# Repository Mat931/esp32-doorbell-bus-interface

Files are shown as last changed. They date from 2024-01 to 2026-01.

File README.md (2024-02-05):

# ESP32 Bus Interface for ABB-Welcome and Busch-Welcome 
This device allows you to integrate your ABB-Welcome or Busch-Welcome 2-wire doorbell intercom system into Home Assistant. Features include doorbell notifications and remotely opening your door. You can order the fully assembled board from a PCB manufacturer.

[How to order](https://github.com/Mat931/esp32-doorbell-bus-interface/blob/main/how_to_order.md)

[How to flash with ESPHome](https://github.com/Mat931/esp32-doorbell-bus-interface/blob/main/how_to_flash.md)

[How to customize for your system](https://github.com/Mat931/esp32-doorbell-bus-interface/blob/main/how_to_customize.md)

### Example applications
- Get notified when someone rings your doorbell
- Open your front door using your smartphone
- Build external door opener buttons that also stop the doorbell ringtone
- Turn on the hallway lights from Home Assistant
- Send and receive any control message on the ABB-Welcome 2-wire bus

### Limitations
- Only works with 2-wire systems, not ABB-Welcome IP
- Audio and video is not supported by this hardware

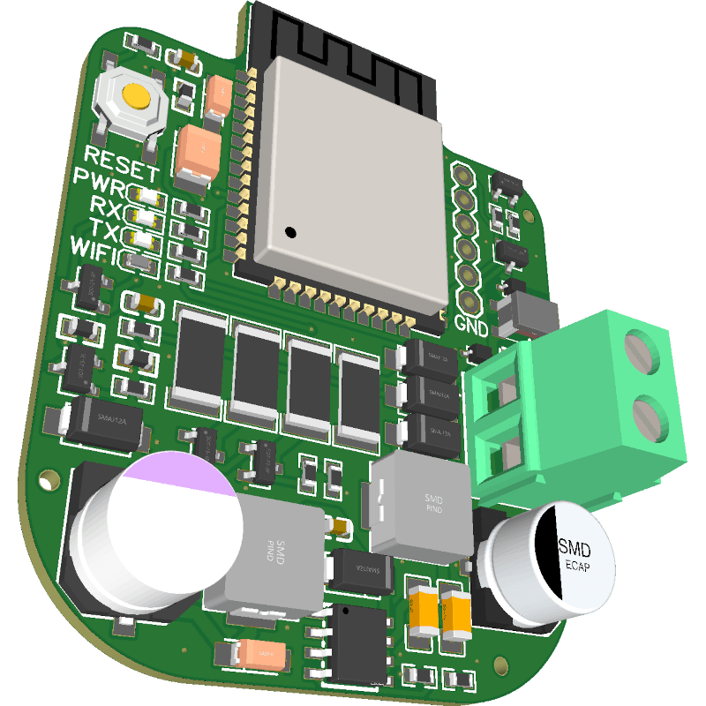
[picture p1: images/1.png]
PCB image


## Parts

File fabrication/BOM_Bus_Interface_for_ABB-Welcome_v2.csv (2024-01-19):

ID | Name | Designator | Footprint | Quantity | Manufacturer Part | Manufacturer | Supplier | Supplier Part | Price
1 | 10nF | C1 | C0603 | 1 | 0603B103K500NT | FH(风华) | LCSC | C57112 | 0.003
2 | 10uF | C2,C4 | CAP-SMD_L3.2-W1.6-RD-C7171 | 2 | TAJA106K016RNJ | Kyocera AVX | LCSC | C7171 | 0.097
3 | 68nF | C3 | C0603 | 1 | CL10B683KB8NNNC | SAMSUNG(三星) | LCSC | C31658 | 0.008
4 | 100nF | C5 | C0603 | 1 | CC0603KRX7R9BB104 | YAGEO(国巨) | LCSC | C14663 | 0.002
5 | 100uF | C6 | CASE-B_3528 | 1 | TAJB107K006RNJ | Kyocera AVX | LCSC | C16133 | 0.142
6 | 2.2uF | C7,C8 | C1206 | 2 | CL31B225KBHNNNE | SAMSUNG(三星) | LCSC | C50254 | 0.027
7 | 470uF | C19 | CAP-SMD_BD8.0-L8.3-W8.3-LS9.0-FD | 1 | RVT470UF16V67RV0031 | KNSCHA(科尼盛) | LCSC | C2858857 | 0.065
8 | 100uF | C23 | CAP-SMD_BD8.0-L8.3-W8.3-RD | 1 | VEJ101M1HTR-0810 | Lelon | LCSC | C176665 | 0.084
9 | SS24 | D1,D2,D3,D4,D5 | SMA_L4.3-W2.6-LS5.0-FD | 5 | SS24 | 宏迦橙 | LCSC | C7420362 | 0.019
10 | SD36C_C502537 | D6,D7 | SOD-323_L1.7-W1.3-LS2.7-BI | 2 | SD36C | MDD | LCSC | C502537 | 0.033
11 | nSMD005 | F2 | F1206 | 1 | nSMD005 | TECHFUSE | LCSC | C70064 | 0.032
12 | ACT45B-510-2P-TL003 | L1 | IND-SMD_4P-L4.5-W3.2-TL | 1 | ACT45B-510-2P-TL003 | TDK | LCSC | C76584 | 0.356
13 | 100uH | L2,L3 | IND-SMD_L7.1-W6.6 | 2 | SMMS0650-101M | SXN(顺翔诺) | LCSC | C2894722 | 0.147
14 | Red | LED1 | LED0603-RD | 1 | KT-0603R | KENTO | LCSC | C2286 | 0.006
15 | Yellow | LED2,LED3 | LED0603-RD-YELLOW | 2 | 19-213/Y2C-CQ2R2L/3T(CY) | EVERLIGHT(亿光) | LCSC | C72038 | 0.021
16 | White | LED4 | LED0603-R-RD_WHITE | 1 | KT-0603白灯 | KENTO | LCSC | C2290 | 0.01
17 | WJ500V-5.08-2P-14-00A | P1 | CONN-TH_2P-P5.00_WJ500V-5.08-2P | 1 | WJ500V-5.08-2P | KANGNEX(康奈克斯电气) | LCSC | C8465 | 0.094
18 | S8050_C2146 | Q1,Q2,Q3 | SOT-23-3_L3.0-W1.7-P0.95-LS2.9-BR | 3 | S8050 J3Y | CJ(江苏长电/长晶) | LCSC | C2146 | 0.014
19 | 2N7002 | Q4,Q5,Q6 | SOT-23-3_L2.9-W1.3-P1.90-LS2.4-BR | 3 | 2N7002 | CJ(江苏长电/长晶) | LCSC | C8545 | 0.015
20 | 100kΩ | R1,R8,R9 | R0603 | 3 | 0603WAF1003T5E | UNI-ROYAL(厚声) | LCSC | C25803 | 0.001
21 | 10K | R2,R3,R10 | R0603 | 3 | 0603WAF1002T5E | UniOhm | LCSC | C25804 | 0.001
22 | 1kΩ | R4,R5,R6,R17 | R0603 | 4 | 0603WAF1001T5E | UNI-ROYAL(厚声) | LCSC | C21190 | 0.001
23 | 75Ω | R7 | R0603 | 1 | 0603WAF750JT5E | UNI-ROYAL(厚声) | LCSC | C4275 | 0.001
24 | 150Ω | R11,R16,R20 | R0603 | 3 | 0603WAF1500T5E | UNI-ROYAL(厚声) | LCSC | C22808 | 0.001
25 | 820Ω | R12,R13,R14,R15 | R2512 | 4 | FRC2512F8200TS | FOJAN(富捷) | LCSC | C2999541 | 0.024
26 | 3.3kΩ | R18 | R0603 | 1 | 0603WAF3301T5E | UNI-ROYAL(厚声) | LCSC | C22978 | 0.001
27 | 5.6kΩ | R19 | R0603 | 1 | 0603WAF5601T5E | UNI-ROYAL(厚声) | LCSC | C23189 | 0.001
28 | TS-1187A-B-A-B | SW1 | SW-SMD_4P-L5.1-W5.1-P3.70-LS6.5-TL-2 | 1 | TS-1187A-B-A-B | XKB Connectivity(中国星坤) | LCSC | C318884 | 0.016
29 | TPS5430DDAR | U1 | ESOP-8_L4.9-W3.9-P1.27-LS6.0-TL-EP | 1 | TPS5430DDAR | TI(德州仪器) | LCSC | C9864 | 0.543
30 | ESP32-SOLO-1 | U2 | WIFIM-SMD_38P-L25.5-W18.0-P1.27 | 1 | ESP32-SOLO-1 | ESPRESSIF(乐鑫) | LCSC | C473005 | 2.988

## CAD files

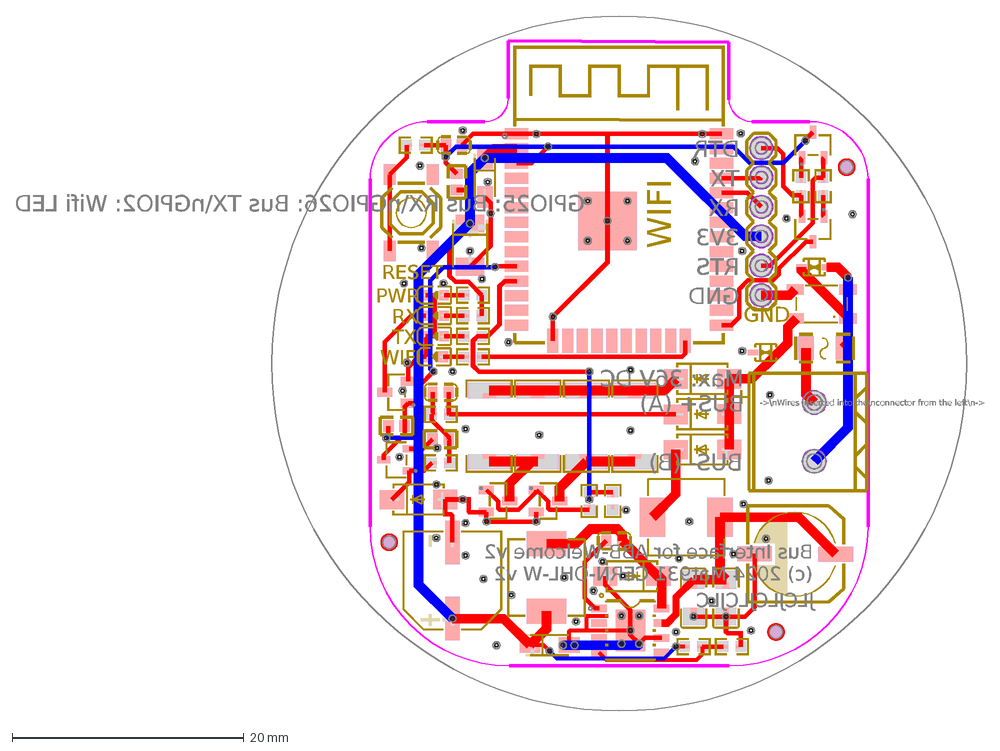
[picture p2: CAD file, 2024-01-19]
design/Bus_Interface_for_ABB-Welcome_v2.dxf
->\nWires inserted into the\nconnector from the left\n->
PWR
RX
TX
WIFI
RESET
+
-
JLCJLCJLCJLC
DTR
3V3
RTS
GND
BUS- (B)
BUS+ (A)
Max: 36V DC
Bus Interface for ABB-Welcome v2
(c) 2024 Mat931 CERN-OHL-W v2
GPIO25: Bus RX\nGPIO26: Bus TX\nGPIO2: Wifi LED

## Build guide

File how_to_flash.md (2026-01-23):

The ESP32 on this board must be programmed with a firmware like [ESPHome](https://esphome.io/).

## ESPHome Example Configuration
```yaml
esp32:
  board: esp32dev
  framework:
    type: esp-idf
    sdkconfig_options:
      CONFIG_FREERTOS_UNICORE: y # Only required if you have a single core ESP32

esphome:
  name: abb-welcome-demo
  friendly_name: "ABB Welcome Demo"
  on_boot:
    - lock.template.publish:
        id: front_door
        state: LOCKED
    - binary_sensor.template.publish:
        id: doorbell_indoor
        state: OFF
    - binary_sensor.template.publish:
        id: doorbell_outdoor
        state: OFF

wifi:
  networks:
    - ssid: !secret wifi_ssid
      password: !secret wifi_password

logger:

api:
  encryption:
    key: !secret api_encryption_key

ota:
  - platform: esphome
    password: !secret ota_password

remote_transmitter:
  pin: GPIO26
  carrier_duty_percent: 100%
  non_blocking: true

remote_receiver:
  pin:
    number: GPIO25
    mode:
      input: True
  dump: [abbwelcome]
  filter: 8us
  tolerance:
    type: time
    value: 26us
  idle: 1500us
  buffer_size: 15kB
  rmt_symbols: 320
  clock_resolution: 500000
  on_abbwelcome:
    then:
      - lambda: "char buf[192]; x.format_to(buf, 192); id(doorbell_intercom).publish_state(buf);"
      - if:
          condition:
            and:
              - lambda: "return (x.get_message_type() == 0x8d);" # unlock door response
              - lambda: "return (x.get_source_address() == 0x4001);" # door address
          then:
            - lock.template.publish:
                id: front_door
                state: UNLOCKING
            - delay: 3s # time how long the door usually stays unlocked
            - lock.template.publish:
                id: front_door
                state: LOCKED
      - if:
          condition:
            and:
              - lambda: "return (x.get_message_type() == 0x11);" # doorbell indoor
              - lambda: "return (x.get_source_address() == 0x1001);" # your indoor station address
          then:
            - binary_sensor.template.publish:
                id: doorbell_indoor
                state: ON
            - binary_sensor.template.publish:
                id: doorbell_indoor
                state: OFF
      - if:
          condition:
            and:
              - lambda: "return (x.get_message_type() == 0x01);" # doorbell outdoor
              - lambda: "return (x.get_source_address() == 0x2001);" # outdoor station address
              - lambda: "return (x.get_destination_address() == 0x1001);" # your indoor station address
          then:
            - binary_sensor.template.publish:
                id: doorbell_outdoor
                state: ON
            - binary_sensor.template.publish:
                id: doorbell_outdoor
                state: OFF

binary_sensor:
  - platform: template
    name: Doorbell indoor
    id: doorbell_indoor
    icon: mdi:bell
    filters:
      - delayed_off: 1s
  - platform: template
    name: Doorbell outdoor
    id: doorbell_outdoor
    icon: mdi:bell
    filters:
      - delayed_off: 1s

sensor:
  - platform: internal_temperature
    name: "Internal Temperature"

text_sensor:
  - platform: template
    name: "Doorbell Intercom" # Receive debug messages
    id: doorbell_intercom
    icon: mdi:bell-circle
    update_interval: never

lock:
  - platform: template
    name: "Front Door"
    id: front_door
    on_unlock:
      - then:
          - lock.template.publish:
              id: front_door
              state: LOCKED
    lock_action:
      - then:
          - lock.template.publish:
              id: front_door
              state: LOCKED
    unlock_action:
      - then:
          - remote_transmitter.transmit_abbwelcome:
              source_address: 0x1001 # your indoor station address
              destination_address: 0x4001 # door address
              three_byte_address: false # address length of your system
              message_type: 0x0d # unlock door
              data: [0xab, 0xcd, 0xef] # door opener secret code, see receiver dump

button:
  - platform: restart
    name: "Reboot"
  - platform: safe_mode
    name: "Reboot (Safe Mode)"
  - platform: template
    name: "Stop Doorbell"
    on_press:
      - remote_transmitter.transmit_abbwelcome:
          source_address: 0x1001 # your indoor station address
          destination_address: 0x2001 # outdoor station address
          three_byte_address: false # address length of your system
          message_type: 0x02 # end call (stops your doorbell ringtone)
          data: [0x00]

status_led:
  pin:
    number: GPIO2
    ignore_strapping_warning: true
```

## Flashing

For flashing you need a USB-to-serial adapter that supports 3.3V and has the required pins. The board includes an auto-reset circuit so you don't need to manually ground GPIO0 or press any buttons during flashing. The rest of the flashing process is identical to other ESP32 and ESPHome devices.

| USB-to-serial adapter | Programming header of the board |
| --- | --- |
| VCC | 3V3 |
| GND | GND |
| TX | RX |
| RX | TX |
| DTR | DTR |
| RTS | RTS |

If your USB-to-serial adapter can't supply enough power to flash the ESP32 you can disconnect `3V3` and connect an external power supply (12-30V DC) to the `BUS+` and `BUS-` pins.

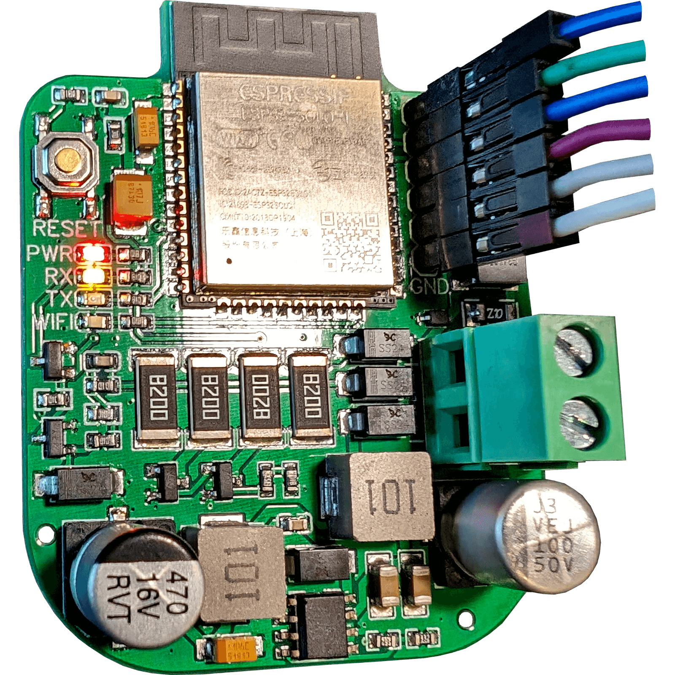
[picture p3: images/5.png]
PCB image
 

## Installation

Before connecting the device to the ABB-Welcome bus it is recommended to check the bus voltage. It should be between 20V and 30V DC. Above 36V the device can take damage. Connect the positive wire to `BUS+` and the negative wire to `BUS-`. If the TX LED lights up continuously after connecting you should disconnect the wires and check your yaml configuration. The device has protection against reverse polarity and a resettable fuse.

Note: You are responsible for connecting the device to your system and for the firmware you upload. The author of this project takes no responsibility for any damages.

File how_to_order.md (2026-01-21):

## How to order

### JLCPCB with assembly:

- Go to https://cart.jlcpcb.com/quote
- Upload the [Gerber file](https://github.com/Mat931/esp32-doorbell-bus-interface/tree/main/fabrication)
- Choose a color and thickness combination that is compatible with assembly (Recommended is green and 1.6mm, more info at https://jlcpcb.com/capabilities/pcb-assembly-capabilities)
- Optional: Select `Mark on PCB: Order Number (Specify Position)`
- Scroll down to `PCB Assembly` and turn on the switch
- Make sure `Economic` and `Top Side` are selected
- Select `Quantity (PCBA Qty): 2` or `5` depending on how many assembled boards you want to order
- Select `Tooling holes: Added by Customer`
- Under `Assembly` - `Advanced Options` select `PCBA remark: Yes` remark and add the text `P1 orientation is correct` and click `Save`
- Click `Next`
- Upload the [BOM and CPL files](https://github.com/Mat931/esp32-doorbell-bus-interface/tree/main/fabrication)
- Click `Process BOM & CPL`
- If you get the message `P2 designator don't exist in the BOM file` click `Continue`
- Make sure every component in the list is in stock and has a check mark on the right
- If some components are out of stock you can replace them with similar parts
- Click `Next` twice
- Select a product description, for example `Research/Education/DIY/Entertainment` and `Development Board`
- Save to cart

### What you will receive (Example):

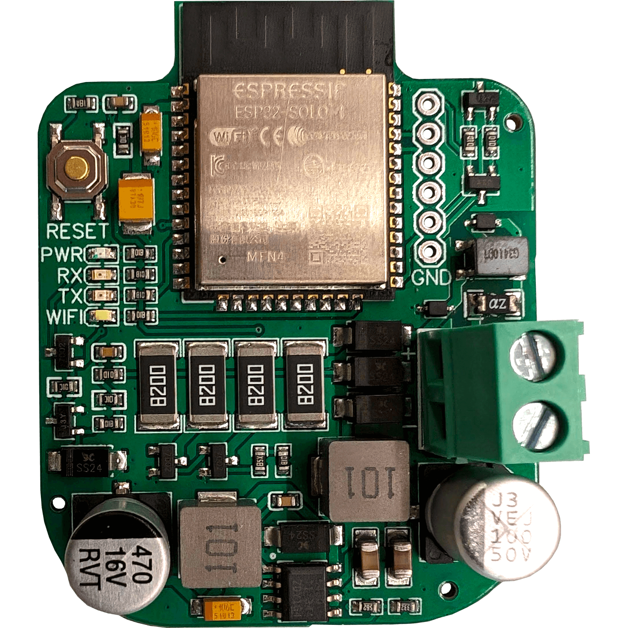
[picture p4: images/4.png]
PCB image


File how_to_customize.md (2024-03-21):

After uploading the [basic configuration](https://github.com/Mat931/esp32-doorbell-bus-interface/blob/main/how_to_flash.md#esphome-example-configuration) to the ESP32 and connecting the board to your doorbell intercom you need to customize the configuration for your specific system.

## Basics

- Press the `Logs` button in the ESPHome dashboard to observe received messages.
- Alternatively after connecting the board to Home Assistant you can use the debug sensor named `Doorbell Intercom` for long-term observation of received messages.
- Received messages are structured like this:
  - `55.FF.XX...XX (10)`: Raw data in hexadecimal format and message length.
  - `[XXXX > XXXX]`: Source and destination addresses, `»` means the message is a retransmission. If you see six characters (`XXXXXX`) instead of four your system is using three-byte addresses. When transmitting messages you need to add `three_byte_address: true` in the ESPHome config. More info about addresses is available [here](https://github.com/Mat931/esp32-doorbell-bus-interface/wiki/Address-Types).
  - `Type: XX`: Message type, if it's 0x80 or above then the message is a reply. For example if the initial message has type `01` then the reply type will be `81`. More info about message types is available [here](https://github.com/Mat931/esp32-doorbell-bus-interface/wiki/Message-Types).
  - `Data: XX` Data attached to the message (optional). The meaning of the data depends on the message type.

## Receiving doorbell notifications

- Ring your doorbell and write down the exact time.
- Check the log and write down all messages that were transmitted at that time or 1-2 seconds later.
- To avoid false positives start a manual video or call to the outdoor station and compare all received messages to the ones written down in the last step. If some messages are identical they can't be used for doorbell notifications. Remove them from your notes.
- Find your indoor station's address. It was probably the source or destination of most received messages. Indoor station addresses can start for example with `10XX` or `0001XX`. The last two characters of the address represent the apartment number set by the dials on the back of your indoor station and are displayed in hexadecimal format. For example if the dials are set to `12` (decimal) then the last two characters of the address will be `0c` (hexadecimal).
- Messages that have your indoor station address as source, destination or in the data can be used for doorbell notifications. For increased reliability it is best to use multiple message types.

```yaml
      - if:
          condition:
            or:
              # Type 01, Outdoor Station (0x2001) > Indoor Station #12 (0x100c)
              - lambda: 'return (x.get_message_type() == 0x01) && (x.get_source_address() == 0x2001) && (x.get_destination_address() == 0x100c);'
              # Type 81, Indoor Station #12 (0x100c) > Outdoor Station (0x2001)
              - lambda: 'return (x.get_message_type() == 0x81) && (x.get_source_address() == 0x100c) && (x.get_destination_address() == 0x2001);'
              # Type 0a, Outdoor Station (0x2001) > Gateway (0x3001), Data contains indoor station address (0x10, 0x0c)
              - lambda: 'std::vector<uint8_t> d = {0x01, 0x10, 0x0c}; return (x.get_message_type() == 0x0A) && (x.get_source_address() == 0x2001) && (x.get_destination_address() == 0x3001) && (x.get_data() == d);'
          then:
          - binary_sensor.template.publish:
              id: doorbell_outdoor
              state: ON
          - binary_sensor.template.publish:
              id: doorbell_outdoor
              state: OFF
```

- For indoor doorbells fewer messages are transmitted.

```yaml
      - if:
          condition:
            or:
              # Type 11, Source: Indoor Station (0x100C)
              - lambda: 'return (x.get_message_type() == 0x11) && (x.get_source_address() == 0x100c);'
              # Type 91, Destination: Indoor Station (0x100C)
              - lambda: 'return (x.get_message_type() == 0x91) && (x.get_destination_address() == 0x100c);'
          then:
          - binary_sensor.template.publish:
              id: doorbell_indoor
              state: ON
          - binary_sensor.template.publish:
              id: doorbell_indoor
              state: OFF
```

## Opening your front door

- Press the door opener button on your indoor station and write down the exact time. Activating the display of your indoor station might already send some irrelevant messages.
- Check the log and write down all messages that were transmitted at that time or 1-2 seconds later.
- Look for a message with type `0d` or `0e`. Use that message's addresses, type and data in your config. If there are none, you need to find the right message by trial and error.

```yaml
on_...:
  - remote_transmitter.transmit_abbwelcome:
      source_address: 0x100c # your indoor station address
      destination_address: 0x4001 # door address
      three_byte_address: false # address length of your system
      message_type: 0x0d # unlock door
      data: [0xab, 0xcd, 0xef] # message data
```

- To provide feedback to Home Assistant when the door has been opened look for a message with type `8d` or `8e`.

```yaml
      - if:
          condition:
            and:
              - lambda: 'return (x.get_message_type() == 0x8d);' # Door opener response
              - lambda: 'return (x.get_source_address() == 0x4001);' # Door address
          then:
          - lock.template.publish:
              id: main_door
              state: UNLOCKING
          - delay: 3s # How long the door usually stays unlocked
          - lock.template.publish:
              id: main_door
              state: LOCKED
```

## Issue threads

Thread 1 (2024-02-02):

[Feature Request] plain board design without esp32

m-idler, 2024-02-02:
I'm really keen on the project and would love to try it out as soon as possible. One thing that I'm struggling with, is the possibility to either use it with an existing esp32/esphome or somehow get a wired ethernet connection available (i would prefer to install it close to the welcome module in the distribution cabinet). As I understood so far, connecting an ethernet chip via pins/wires wouldn't be a very reliable solution, so i guess a generic board without an hardwired esp, just with a pin interface for external boards would be really helpful. Unfortunately I haven't any experience in circuit board design / modification yet and expect it to be a pretty error-prone way for a newbie. Maybe someone could help here to make this really cool hardware and the implementation in esphome available to even more people.
Thank you

Mat931, 2024-02-03:
I designed the board so that it can work and receive power from the bus without any external cables. If you want to connect things like ethernet or external power I don't know what effects that will have on the ABB-Welcome system (maybe reduced video and audio quality or worse?) so you need to consider isolating the bus interface from the rest of your circuit. In my experience the wifi connection of the ESP32 is reliable enough for this project, that's why I picked it over an ESP8266. Not sure what you have in mind for your "generic board". Should it supply power from the bus or are you planning to use an external supply? I guess you could make a minimal board with just the transmit and receive circuit, protection and two optoisolators.

m-idler, 2024-02-03:
Yes i think that would be a good idea to have a minimal board, that just contains the transmit and receive circuit, protection , the optoisolators and pin connectors to connect the rx/tx pins (and maybe other needed pins) to a separate esp32 (e.g. one of the olimex boards with included ethernet).
Unfortunately i don't have a licence of altium designer to (at least) try stripping down the current board to a minimal one. I tried importing it to KiCad - PCB Editor but unfortunately just get an error "Wrong file format". :(

Mat931, 2024-02-03:
I used [EasyEDA](https://easyeda.com/editor) to design the circuit. The other file formats are just exported from there. I think you can even use it without an account if you upload the EasyEDA JSON files. I just noticed that I forgot to export and upload the schematic file, it needs to be exported separately. Now all the required files are in the repo.

LorbusChris, 2024-05-03:
Awesome project, thanks @Mat931!

You may want to consider the [Feather / FeatherWing form factor]( https://learn.adafruit.com/adafruit-feather/feather-specification ) for an MCU-agnostic board.

Feathers are the the MCU base boards. There are many Feather spec-compatible boards with different MCUs available from different manufacturers, e.g. Adafruit, Sparkfun (Thing Plus), ThingPulse (ePulse), and more.

FeatherWings are the add-on boards that stack on top for io extension (even multiple).
A quick search turned up that there are already a [CAN Bus FeatherWing](https://learn.adafruit.com/adafruit-can-bus-featherwing/overview), [M-Bus FeatherWing](https://www.hwhardsoft.de/deutsch/projekte/m-bus-featherwing/) and even a [Power-over-Ethernet FeatherWing](https://silicognition.com/Products/poe-featherwing/) as an example of one that powers the Feather from the bus.

nils1981, 2024-10-30:
Very nice project - thank you for sharing! As the Minimum Order quantity is 2 or 5 - someone in Germany wants to sell a board?

Mat931, 2024-11-07:
@Haych One other thing my PCB does is power the ESP32 from the doorbell bus. If you're using an external power supply it might have unintended side effects like worse video and audio quality, I haven't really tested that.

Mat931, 2024-11-07:
> I don’t suppose video and audio integration is on your roadmap?
Not for this project. I meant the video and audio quality of your or other indoor stations. The signal is sent in analog form over the same two wires. Electrical noise from a power supply might make it worse.

Chillidaddy, 2024-11-12:
> Very nice project - thank you for sharing! As the Minimum Order quantity is 2 or 5 - someone in Germany wants to sell a board?

Germany here too. Maybe a group buy?

RoMaTiX99, 2024-11-14:
Hey @Chillidaddy , @nils1981 . Just saw your comments - I'm from Germany too and highly-interested.
So already 3 of us. Group buy sounds great.

Costs would be about 75€ in total. /3 makes roughly 25€ p.P. Sound's great, isn't it?
Should we do it?

nils1981, 2024-11-14:
Hi @RoMaTiX99, Hi @Chillidaddy
yes - I am very much interested.
I will contact you seperately with the email from your profile.

nils1981, 2024-11-23:
Hi @FloMeyer,
There is 1 last board left. Expecting delivery next week.

FloMeyer, 2024-11-23:
> Hi @FloMeyer, There is 1 last board left. Expecting delivery next week.

Nice, i‘ll take ist. Can you sent me an email? Do you see it in my Profile? (Should be public)

LorbusChris, 2024-11-23:
I have one spare device that I'd sell at cost. Feel free to send an email (see my git commits).

BreBarMevco, 2025-05-17:
Hey all great project and thanks @Mat931

My boards have just arrived in Australia, I have 4 spares also happy to sell at cost + shipping.

Anyone who needs one yell out!

BreBar07, 2025-05-17:
Hey all, first thanks @Mat931 amazing project.

Just received my 5 complete boards, I only need one.

Anyone who needs one yell out happy to sell at cost + shipping, I’m based in Australia.

Thanks!

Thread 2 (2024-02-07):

[Feature Request] Enable wiki on the repo to better document the protocol

mallorca2288, 2024-02-07:
First of all, I want to thank the author for taking the time and effort to do this fantastic project. I've been using it for a few weeks and it works wonderfully.

I've tried to find documentation on how the communication protocol works, but I have not been able to find much information.

I think it would be useful if the repository wiki was activated so that people can add everything they discover about the protocol.

For now the little information I have found is the following:

Message Types:
```
DoorbellOutdoor = 0x01,
EndCall = 0x02,
AcceptCall = 0x03,
ManualVideo = 0x04,
Light = 0x09,
Call = 0x0a,
Door = 0x0d,
DoorbellIndoor = 0x11,
Actor = 0x16,
Video = 0x52,
```

Device Types:
```
IndoorStation = 0x1,
OutdoorStation = 0x2,
Gateway = 0x3,
Relay = 0x4,
Actor = 0x8,
Video = 0x9,
```

My system also sends messages with the following message type codes: 0x0B, 0xA0, 0x20, 0x60, 0xA2 but I don't know what they mean.

Mat931, 2024-02-07:
Great idea to start a wiki! I'm not sure about the data format either, these are just guesses what the messages could mean. Some more reverse engineering is definitely needed.

Mat931, 2024-02-07:
I added some of the message types I found [here](https://github.com/Mat931/esp32-doorbell-bus-interface/wiki/Message-Types). If you have some new info or a guess what messages could mean please tell me!

mallorca2288, 2024-02-07:
I've found that changing the password to open the door on the indoor unit will send a 0x0F message with the password in the Data. I don't get any reply to this message.

For example, setting the password to 123456 will send the following message:
`55.FF.46.0F.FF.02.FF.00.01.08.C0.02.01.12.34.56.FF.03 (18) [000108 > FF02FF] Type: 0F, Data: 02.01.12.34.56.FF (6)`

Setting the password to 555555 will send the following message:
`55.FF.46.0F.FF.02.FF.00.01.08.35.02.01.55.55.55.FF.A8 (18) [000108 > FF02FF] Type: 0F, Data: 02.01.55.55.55.FF (6)`

Disabling the password:
`55.FF.46.0F.FF.02.FF.00.01.08.E8.02.00.55.55.55.FF.1C (18) [000108 > FF02FF] Type: 0F, Data: 02.00.55.55.55.FF (6)`

So the second part of the data tells the "controller" if the password is enabled = 01 or disabled = 00 and the third, fourth and fifth parts are the password.

mallorca2288, 2024-02-07:
0x1A message is sent together with a 0x0A message when calling the guard-unit from the indoor unit.

In my building there isn't a guard-unit, I suppose that's why I don't get any response.

dgomes, 2024-02-11:
Some more information to help sort the protocol out:

I have a single home systems composed of controller, outdoor unit and indoor unit.

The following debug is a session in which the outdoor unit started a call, the indoor unit answered and later pressed the unlock button.

```
[17:00:37][I][remote.abbwelcome:110]: Received: 55.FF.42.0A.00.01.01.00.02.01.2B.01.15.D9 (14) [000201 > 000101] Type: 0A, Data: 01.15
[17:00:37][I][remote.abbwelcome:110]: Received: 55.FF.42.0B.00.01.01.00.02.01.2B.81.15.72 (14) [000201 > 000101] Type: 0B, Data: 81.15
[17:00:37][I][remote.abbwelcome:110]: Received: 55.FF.42.8B.00.02.01.00.01.01.2B.01.15.BA (14) [000101 > 000201] Type: 8B, Data: 01.15
[17:00:37][I][remote.abbwelcome:110]: Received: 55.FF.42.8A.00.02.01.00.01.01.2B.8B.15.13 (14) [000101 > 000201] Type: 8A, Data: 8B.15
[17:00:37][I][remote.abbwelcome:110]: Received: 55.FF.45.01.00.01.01.00.02.01.9D.28.15.01.1E.11.ED (17) [000201 > 000101] Type: 01, Data: 28.15.01.1E.11 (5)
[17:00:37][I][remote.abbwelcome:110]: Received: 55.FF.44.81.00.02.01.00.01.01.9D.29.01.1E.11.9D (16) [000101 > 000201] Type: 81, Data: 29.01.1E.11
[17:00:37][I][remote.abbwelcome:110]: Received: 55.FF.4A.23.00.20.FF.00.02.01.F7.02.00.00.00.00.00.00.00.00.00.7F (22) [000201 > 0020FF] Type: 23, Data: 02.00.00.00.00.00.00.00.00.00 (10)
[17:00:40][I][remote.abbwelcome:110]: Received: 55.FF.45.01.00.02.01.00.01.01.D4.00.15.03.78.11.6F (17) [000101 > 000201] Type: 01, Data: 00.15.03.78.11 (5)
[17:00:40][I][remote.abbwelcome:110]: Received: 55.FF.44.81.00.01.01.00.02.01.D4.29.03.78.11.15 (16) [000201 > 000101] Type: 81, Data: 29.03.78.11
[17:00:45][I][remote.abbwelcome:110]: Received: 55.FF.41.0E.00.04.01.00.01.01.D0.00.79 (13) [000101 > 000401] Type: 0E, Data: 00
[17:00:45][I][remote.abbwelcome:110]: Received: 55.FF.41.8E.00.01.01.00.04.01.D0.00.95 (13) [000401 > 000101] Type: 8E, Data: 00
[17:00:45][I][remote.abbwelcome:110]: Received: 55.FF.44.35.00.13.01.00.02.01.2F.00.02.01.01.0D (16) [000201 > 001301] Type: 35, Data: 00.02.01.01
[17:00:46][I][remote.abbwelcome:110]: Received: 55.FF.C4.35.00.13.01.00.02.01.2F.00.02.01.01.EE (16) [000201 » 001301] Type: 35, Data: 00.02.01.01
[17:00:46][I][remote.abbwelcome:110]: Received: 55.FF.C4.35.00.13.01.00.02.01.2F.00.02.01.01.EE (16) [000201 » 001301] Type: 35, Data: 00.02.01.01
[17:00:50][I][remote.abbwelcome:110]: Received: 55.FF.41.02.00.02.01.00.01.01.0F.00.12 (13) [000101 > 000201] Type: 02, Data: 00
[17:00:50][I][remote.abbwelcome:110]: Received: 55.FF.40.82.00.01.01.00.02.01.0F.D9 (12) [000201 > 000101] Type: 82
```

0x0201 is the outdoor unit
0x0101 is the indoor unit

don't know what is 0x0401 nor 0x1301

mallorca2288, 2024-02-11:
> don't know what is 0x0401 nor 0x1301

I think 0x000401 might be the address of the actuator unit that unlocks your door.

For example this is what unlocks the doors in my apartment:
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

dgomes, 2024-02-11:
pretty sure I don't have that ... the door is connected to the outside unit directly

mallorca2288, 2024-02-11:
I just checked my installation and some doors are connected directly to the outdoor unit as you indicate.

In units where the door is directly connected without a separate actuator, the same unit has different addresses for different functions.

For example, my south outdoor unit has the following addresses:
3E0204 to make/receive calls (Code 0x01 and 0x81)
3E0404 to unlock the directly connected door (Code 0x0e and 0x8e)
000205 to turn lights on/off? (Code 0x09)

Closed 2024-08-26.

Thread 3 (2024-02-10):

Unable to flash using esphome

vr-hunter, 2024-02-10:
Hey, kudos for this cool project! I just got back the hardware from JLCPCB.

However: I'm unable to flash anything. What I've tried so far:

Resetting the device from web.esphome.io seems to work:
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

Initializing / flashing from the dashboard just hangs at "connecting"

Using the old esphome flashing tool gives me this message:

```
Using 'COM3' as serial port.
Connecting......................................
Unexpected error: ESP is not in flash boot mode. If your board has a flashing pin, try again while keeping it pressed.
```

I'm quite new to esphome, any ideas as to where I went wrong?

(I'm supplying the device externally with 30V)

vr-hunter, 2024-02-11:
I managed to flash the image manually using esptool.

Closed 2024-02-11.

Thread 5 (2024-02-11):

[Question] PCB Housing

vr-hunter, 2024-02-11:
Hey @Mat931, thanks again for this awesome project! Mine is working nicely so far!

Since my PCB is currently dangling from the bus lines, I was wondering if you chose the PCB with an existing housing in mind?
If not, would it be possible to share the 3D model as a step file?

Mat931, 2024-02-11:
Hi @vr-hunter!
I designed the board so it can fit in a 60mm diameter circle (flush mounted wall box) with not much room to spare. If you need a 3D model of the board you can import the PCB file into EasyEDA and export an OBJ file from there.

vr-hunter, 2024-02-12:
Gotcha, I'll try and export it from there. If I can find some time for it, I'll probably design a small wall-mountable enclosure.

Closed 2024-02-12.

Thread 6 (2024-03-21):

[Bug] Addresses transmitted trimmed

rodricels, 2024-03-21:
First of all, thank you very much for your work releasing the design of the boards and investigating the ABB protocol, it is a magnificent job.

I am trying to run the project in a 200+ apartment community and I may have encountered a strange case with the addresses (or something I am doing terribly wrong). The addresses logged are padded with zeros but the transmission seems to remove them, the commands sent do nothing to the doors.

```
unlock_action:
  - then:
      - remote_transmitter.transmit_abbwelcome:
          source_address: 0x000110 # indoor station address, tried with 0x0110 and sends the same bytes
          destination_address: 0x000401 # building door address, tried with 0x0410 and sends the same bytes
          message_type: 0x0e # unlock door
          data: [0x00]  # door opener secret code, see receiver dump
```

```
Press the unlock button on the indoor station:
[00:37:24][D][text_sensor:064]: 'Doorbell Intercom': Sending state '55.FF.41.0E.00.04.01.00.01.10.BC.00.66 (13) [000110 > 000401] Type: 0E, Data: 00'
[00:37:24][D][text_sensor:064]: 'Doorbell Intercom': Sending state '55.FF.41.8E.00.01.10.00.04.01.BC.00.22 (13) [000401 > 000110] Type: 8E, Data: 00'

Send the unlock command
[00:37:33][D][remote.abbwelcome:054]: Transmitting: 55.FF.01.0E.04.01.01.10.2A.00.96 (11) [0110 > 0401] Type: 0E, Data: 00
```

The number of bytes are different, is it possible that the first two zeros are being removed from the addresses?
Am I sending the unlock command wrong?

Mat931, 2024-03-21:
I think you need to set `three_byte_address: true`. Here's more info: https://github.com/Mat931/esp32-doorbell-bus-interface/blob/main/how_to_customize.md#basics

rodricels, 2024-03-21:
Totally right 😓

Closed 2024-03-21.

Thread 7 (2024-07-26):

Problems with flashing the device

mikkelke, 2024-07-26:
Hi,

TLDR: I always get Failed to connect to ESP32: No serial data received.

I have tried flashing the device with two CH340G and also from a Raspberry Pie 4. I did not succeed.
Power have been supplied from either the CH340G, the Pi or a connected power supply provided 12V and 3A.
I setup the serial connection using a baudrate of 115200.

I can view the boot log when i attach to the serial port: and pressing the reset button.

ets Jun  8 2016 00:22:57

rst:0x1 (POWERON_RESET),boot:0x13 (SPI_FAST_FLASH_BOOT)
configsip: 0, SPIWP:0xee
clk_drv:0x00,q_drv:0x00,d_drv:0x00,cs0_drv:0x00,hd_drv:0x00,wp_drv:0x00
mode:DIO, clock div:2
load:0x3fff0018,len:4
load:0x3fff001c,len:6932
load:0x40078000,len:13712
load:0x40080400,len:4260
entry 0x400806e4
␛[0;32mI (70) boot: Chip Revision: 1␛[0m
␛[0;32mI (70) boot_comm: chip revision: 1, min. bootloader chip revision: 0␛[0m
␛[0;32mI (39) boot: ESP-IDF v4.0.1-193-ge7ac221 2nd stage bootloader␛[0m
␛[0;32mI (39) boot: compile time 02:45:47␛[0m
␛[0;32mI (39) boot: Enabling RNG early entropy source...␛[0m
␛[0;32mI (44) boot: SPI Speed      : 40MHz␛[0m
␛[0;32mI (49) boot: SPI Mode       : DIO␛[0m
␛[0;32mI (53) boot: SPI Flash Size : 4MB␛[0m
␛[0;32mI (57) boot: Partition Table:␛[0m
␛[0;32mI (60) boot: ## Label            Usage          Type ST Offset   Length␛[0m
␛[0;32mI (68) boot:  0 phy_init         RF data          01 01 0000f000 00001000␛[0m
␛[0;32mI (75) boot:  1 otadata          OTA data         01 00 00010000 00002000␛[0m
␛[0;32mI (82) boot:  2 nvs              WiFi data        01 02 00012000 0000e000␛[0m
␛[0;32mI (90) boot:  3 at_customize     unknown          40 00 00020000 000e0000␛[0m
␛[0;32mI (97) boot:  4 ota_0            OTA app          00 10 00100000 00180000␛[0m
␛[0;32mI (105) boot:  5 ota_1            OTA app          00 11 00280000 00180000␛[0m
␛[0;32mI (112) boot: End of partition table␛[0m
␛[0;32mI (117) boot_comm: chip revision: 1, min. application chip revision: 0␛[0m
␛[0;32mI (124) esp_image: segment 0: paddr=0x00100020 vaddr=0x3f400020 size=0x29238 (168504) map␛[0m
␛[0;32mI (193) esp_image: segment 1: paddr=0x00129260 vaddr=0x3ffbdb60 size=0x0396c ( 14700) load␛[0m
␛[0;32mI (199) esp_image: segment 2: paddr=0x0012cbd4 vaddr=0x40080000 size=0x00400 (  1024) load␛[0m
␛[0;32mI (200) esp_image: segment 3: paddr=0x0012cfdc vaddr=0x40080400 size=0x03034 ( 12340) load␛[0m
␛[0;32mI (214) esp_image: segment 4: paddr=0x00130018 vaddr=0x400d0018 size=0x106950 (1075536) map␛[0m
␛[0;32mI (602) esp_image: segment 5: paddr=0x00236970 vaddr=0x40083434 size=0x195c8 (103880) load␛[0m
␛[0;32mI (646) esp_image: segment 6: paddr=0x0024ff40 vaddr=0x400c0000 size=0x00064 (   100) load␛[0m
␛[0;32mI (664) boot: Loaded app from partition at offset 0x100000␛[0m
␛[0;32mI (664) boot: Disabling RNG early entropy source...␛[0m
BLUFI BLE is not connected yet
2.1.0
max tx power=78,ret=0

Hope someone can help me flash the devices.

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

Mat931, 2024-07-26:
Are you sure you connected the DTR pin correctly? Your adapter appears to have only CTS and RTS, I don't see a DTR pin.

mikkelke, 2024-07-26:
I ordered this two today. Hope it will solve my problem.
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

Mat931, 2024-07-27:
The red one should work. It's the same I have. It has a DTR pin on the right row.

dtretyakov, 2024-07-28:
Previously I had the same issue with "No serial data received". It was caused by bad contact of pin headers with the board holes.

I moved a bit further, but now stuck with another issue. The flashing page has no detailed steps and mentions:
> The rest of the flashing process is identical to other ESP32 and ESPHome devices.

I, as a newcomer to ESP32 tooling, discovered the following ways to flash firmware:
* [ESPHome Web](https://web.esphome.io/) which also seems to be used in Home Assistant ESPHome add-on.
* `esptool` which is used in various tutorials and in the https://github.com/Mat931/esp32-doorbell-bus-interface/issues/3#issuecomment-1937442936.

For firmware flashing I'm using the [following CP2102N-based adapter](https://www.amazon.de/dp/B09KXT6W46?psc=1) which has required `DTR`/`RTS` pins:

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

## The problem is that both tools are hanging in the "Connecting" state during flashing

During that board is powered up and `PWR`/`RX` LEDs are permanently on.
The adapter has blinking `TX`/`RX` LEDs, but I could not see that `TX` led is lighting up on the board.

### Auto flashing mode

> The board includes an auto-reset circuit so you don't need to manually ground GPIO0 or press any buttons during flashing

I interpret it as follows: connect jumper wires between the board and adapter and plug adapter into the computer.

*Web tool* after few attempts displays "Failed to initialize. Try resetting your device or holding the BOOT button while selecting your serial port until it starts preparing the installation."

`esptool` displays the following:

```sh
> esptool --port COM9 erase_flash
esptool.py v4.8.dev4
Serial port COM9
Connecting......................................

A fatal error occurred: Failed to connect to Espressif device: Wrong boot mode detected (0x13)! The chip needs to be in download mode.
For troubleshooting steps visit: https://docs.espressif.com/projects/esptool/en/latest/troubleshooting.html
```

### Manual flashing mode

The solution for this ["Wrong boot mode detected (0x13)"](https://github.com/espressif/esptool/issues/741) issue is to press the "boot" button before plugging in adapter and when tool attempts "Connecting" release the button.

Since we have the only "Reset" button I tried to use it as a "boot" button. Results are following:

*Web tool*: after releasing reset button adapter starts blinking only `RX` LED. It ends up with the same error as in "Auto" mode.

`esptool`: only after numerous attempts I was able to release "Reset" button on time so both `erase_flash` and `write_flash` commands were successful.

```
> esptool --port COM9 erase_flash
esptool.py v4.8.dev4
Serial port COM9
Connecting.........
Detecting chip type... Unsupported detection protocol, switching and trying again...
Connecting.........
Detecting chip type... ESP32
Chip is ESP32-D0WDQ6 (revision v1.1)
Features: WiFi, BT, Dual Core, 240MHz, VRef calibration in efuse, Coding Scheme None
Crystal is 40MHz
MAC: ec:64:c9:xx:xx:xx
Uploading stub...
Running stub...
Stub running...
Erasing flash (this may take a while)...
Chip erase completed successfully in 14.3s
Hard resetting via RTS pin...
```

```
> esptool -p COM9 write_flash 0x0 abb-welcome-demo.factory.bin
esptool.py v4.8.dev4
Serial port COM9
Connecting.........
Detecting chip type... Unsupported detection protocol, switching and trying again...
Connecting..........
Detecting chip type... ESP32
Chip is ESP32-D0WDQ6 (revision v1.1)
Features: WiFi, BT, Dual Core, 240MHz, VRef calibration in efuse, Coding Scheme None
Crystal is 40MHz
MAC: ec:64:c9:xx:xx:xx
Uploading stub...
Running stub...
Stub running...
Configuring flash size...
Flash will be erased from 0x00000000 to 0x000cdfff...
Compressed 840112 bytes to 529627...
Wrote 840112 bytes (529627 compressed) at 0x00000000 in 48.1 seconds (effective 139.9 kbit/s)...
Hash of data verified.

Leaving...
Hard resetting via RTS pin...
```

After that successful attempt I was not able to reset/flash firmware again. So my susceptions are:
* `esptool` has problems with delays during the Connect attempt. There is an old patch to address related issue: https://github.com/espressif/esptool/issues/741#issuecomment-1326951723
* I still have soldering issues for pin heads on the board.

### Notes

I soldered pin headers for the second board, but it also has the same issues with Connecting state/Wrong boot mode detected (0x13).

I tried flashing on both Windows/macOS laptops.

So I still have no clue how to find a reliable flashing procedure.

Mat931, 2024-07-28:
The Home Assistant ESPHome add-on typically uses the esptool method, which I recommend. (Select "Plug into the computer running ESPHome Dashboard" when installing) I never used the ESPHome Web method and heard that many people have problems with it.

Depending on the ESP32 model you have it might not work at all with the pre-compiled ESPHome binary the web tool uses, because it requires an ESPHome binary compiled with single-core support.

The TX/RX LEDs on the board are not indicating serial communication (flashing firmware) but rather communication with the ABB welcome bus. When the board is not connected to the bus, it's normal for the RX led to be permanently on.

The method I recommend for flashing is using the ESPHome dashboard and connecting the ESP to the computer that's running the dashboard.

Hope this helps :)

mikkelke, 2024-07-31:
TLDR:
Using the red FT232RL flashing was easy and everything works as intended.

First I flashed from my Ubuntu VM on my laptop where i powered the ESP32 model from the Serial Adapter and it flashed as intended, but it did not boot. I got som errors in the log (I did not save them).
Then I connected my 12V DC adapter and flashed from the webinterface of my docker hosted ESPHome thru my Windows laptop in Edge. It flashed without any errors and booted up.

I noted that when you access the log on the ESP32 device the Wi-Fi LED does not blink. It trolled me to believe that the device did not work when i installed it since i left the log window open on my computer.

Anyway everything went smooth and the ESP32 module fit perfectly in the installation box behind my ABB intercom device. I'm very happy with the result . A couple of year ago I changed my ABB intercom indoor device to the one with Wi-Fi and was very sad when I found out it did not support API and there where not great way to interact with the system. I event called ABB and asked if they could provide a solution.
This device provide the missing features and with the bus module and the Wi-Fi intercom I can control programmatically and by video/voice in the ABB app from my phone.

@Mat931 Thank you for creating and sharing this project!

tsgoff, 2024-08-26:
The blue usb serial adapter worked for me.

But somehow I end up in a boot loop:

```
[19:39:49]rst:0x10 (RTCWDT_RTC_RESET),boot:0x13 (SPI_FAST_FLASH_BOOT)
[19:39:49]configsip: 0, SPIWP:0xee
[19:39:49]clk_drv:0x00,q_drv:0x00,d_drv:0x00,cs0_drv:0x00,hd_drv:0x00,wp_drv:0x00
[19:39:49]mode:DIO, clock div:2
[19:39:49]load:0x3f400020,len:43124
[19:39:49]ets Jun  8 2016 00:22:57
[19:39:49]
[19:39:49]rst:0x10 (RTCWDT_RTC_RESET),boot:0x13 (SPI_FAST_FLASH_BOOT)
[19:39:49]configsip: 0, SPIWP:0xee
[19:39:49]clk_drv:0x00,q_drv:0x00,d_drv:0x00,cs0_drv:0x00,hd_drv:0x00,wp_drv:0x00
[19:39:49]mode:DIO, clock div:2
[19:39:49]load:0x3f400020,len:43124
[19:39:49]ets Jun  8 2016 00:22:57
```

is this the correct setting for the new esphome syntax and the correct board?
```
esphome:
  name: esp32-busch-bus
  friendly_name: "esp32-busch-bus"
  on_boot:
    - lock.template.publish:
        id: front_door
        state: LOCKED
    - binary_sensor.template.publish:
        id: doorbell_indoor
        state: OFF
    - binary_sensor.template.publish:
        id: doorbell_outdoor
        state: OFF

esp32:
  board: esp32dev
  framework:
    type: esp-idf
    sdkconfig_options:
      CONFIG_FREERTOS_UNICORE: y
```

Mat931, 2024-08-26:
Hi @tsgoff

it is hard to find the cause of the issue with the limited information you provided. Here are some ideas / questions:
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
Mat931, 2024-08-26:
I think the problem is that you used the ota.bin file with esptool. When flashing via serial you need to use the factory.bin file, the ota one is for updating over wifi.
The command should be: ` esptool.py --port /dev/ttyUSB0 write_flash 0x0 esp32-busch-bus.factory.bin`
Here is some more info on how to use esptool with ESPHome: https://esphome.io/guides/faq#esphome-esptool

tsgoff, 2024-08-26:
thank you!! looks like it is working now!

Closed 2024-08-26.

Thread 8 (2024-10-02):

Spare PCBs

oskarn97, 2024-10-02:
Hey Mat!

Very cool project - I have created a similar device for another manufacturer and now switched flats - the new system is Busch Jäger Welcome. I was wondering if you still have a spare assembled version at hand. Would love to support your work.

Oskar

oskarn97, 2024-10-03:
Thanks for the reply Mat - no worries, will order it from JLC then. Well done, again!

Pixelramp, 2025-01-14:
> Thanks for the reply Mat - no worries, will order it from JLC then. Well done, again!

Sorry for opening this again, did you order a PCB and got one left for me?

Mat931, 2025-01-14:
@oskarn97 Still no. But maybe you can organize a group order with someone else like it was done recently.

oskarn97, 2025-01-14:
I have one left as I had to order two - you can write me on Reddit u/oskarn97

oskarn97, 2025-01-20:
@Pixelramp do you still want one? You didn't reply to my message in reddit.

Pixelramp, 2025-01-21:
@oskarn97 Hey, sorry for the late reply! I’ve got some coming from JLCPCB. A neighbor also wants the PCB.

Closed 2024-10-03.

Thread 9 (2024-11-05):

Wiring Diagram

maximusVII, 2024-11-05:
@Mat931: Thanks a lot for sharing your excellent code and hardware design! Would you mind sharing the wiring diagram? Would it be possible to connect it directly to an indoor station like the Busch-Jaeger 83210?

Mat931, 2024-11-05:
Hi @maximusVII
Not sure which wiring diagram you are looking for. The schematic of the PCB is available [here](https://github.com/Mat931/esp32-doorbell-bus-interface/blob/main/design/Bus_Interface_for_ABB-Welcome_v2.pdf). There is currently no diagram on how to connect it to your Busch-Jaeger system. If your system uses only 2 wires (usually labelled `a1` and `b1`) then it's probably compatible with this project. Based on a quick search I think 83210 is compatible. You just connect the PCB to these 2 wires in parallel with your indoor station with BUS+ going to the positive and BUS- going to the negative wire.

maximusVII, 2024-11-05:
@Mat931: Thanks for your quick response! This is exactly the information I needed. It’s my first time integrating a bus system, and I wasn’t sure if I just needed to connect the ESP-doorbell-bus to a1 and b1 on the indoor station, whether it also requires a separate power source, or if it needs to be connected to another welcome device.

I’ve just ordered 5 devices—if anyone else would like one, let me know!

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

Closed 2024-11-05.

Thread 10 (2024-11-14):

Ready to buy hardware?

RoMaTiX99, 2024-11-14:
Hi there!

I wonder whether anyone has a working pcb laying around at home and is willing to sell it?
I'm not familiar with pcb creation - however I managed to process it on JLCPCB (thanks for the good description!).

For me the price point of roughly 70$ is quite high - especially since I don't need 5 pieces.

So if anybody has some left-overs and is willing to sell them (shipping to Germany) I'd be really grateful!

Best regards!

bladecell, 2024-11-19:
Hey, I have just received 5 of them so I could spare one or two.. send me an email if you are interested.
estate-woozy-broom@duck.com

RoMaTiX99, 2024-11-25:
Hi @bladecell ,

thank you - we managed to organize a group buy in the other open issue. So I don’t have any need currently.

However I will leave this issue open so others can see your offer.

Best!

BreBar07, 2025-05-17:
Hey all,

Just received my 5 complete boards, I only need one.

Anyone who needs one yell out happy to sell at cost + shipping, I’m based in Australia.

Thanks!

mikkelke, 2025-05-22:
Hi!

I have four complete boards that i do not need.
If anyone in Europe need i will sell for the cost + shipping. I'm from Denmark.

Poldo2005, 2025-05-26:
Hi @mikkelke , I'm interested in buying a complete board (or two). Could you send me the price, including shipping costs to Italy, to the address indicated in the image?

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

zeratul021, 2025-06-01:
I would also join the fun if anyone is ordering in bulk to EU (I am in Czechia). Hit me up with pricing details, much appreciated:
range.view6078@eagereverest.com

Chillidaddy, 2025-06-02:
> Hi!
>
> I have four complete boards that i do not need. If anyone in Europe need i will sell for the cost + shipping. I'm from Denmark.

Hello,
from Germany. If you have a board left I’m interested.

popeline-sprueche-0u@icloud.com
(throwaway iCloud Email address.)

klausellus-wallace, 2025-06-03:
I'd like to join the ride too. HMU if you got spare boards flying around, for shipping in EU.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

harl-e, 2025-08-27:
Hello, I am looking for a board at an affordable price with shipping to Germany.
Alternatively, I am also interested in people who want to share the cost of a new order.

JTorkk, 2025-08-28:
> Hello, I am looking for a board at an affordable price with shipping to Germany. Alternatively, I am also interested in people who want to share the cost of a new order.

I have few left and can send to Germany. Send me a email at: [juho@torkke.li](mailto:juho@torkke.li)

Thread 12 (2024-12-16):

Switched BUS+ and BUS-

bladecell, 2024-12-16:
Hey, I am having slight issue with my doorbell, that has polarity of BUS A and B switched meaning that BUS+ is B and BUS- is A. That results in the device not powering on when connected.

When switching cables from my doorbell, connecting BUS A to the BUS- (B) on the board and BUS B to the BUS+ (A) on board the device boots up but when connected simultaneously with the "phone" part of the doorbell it does not receive any messages in log or in HA. I can send messages through HA and see them in logs being transieved but not having my door opened or anything else.

I have tried switching TX and RX pin in the yaml with the switched connection but without any luck, still got none messages received.

So I am wondering if it should work with the switched pins in yaml and the issue is with the board, that I have soldered myself or the issue it somewhere else.

This is my doorbell for reference:

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

Mat931, 2024-12-16:
Hi @bladecell
If the power LED on my board lights up, it's connected correctly. There is no other way to connect it. If the LED doesn't light up, swap the wires. You should not swap the TX and RX pin numbers in the YAML!
With everything connected, try pressing the door opener on your indoor station. You should receive 2 messages. Check the log in ESPHome to see them. From there you can start [customizing the yaml for your system](https://github.com/Mat931/esp32-doorbell-bus-interface/blob/main/how_to_customize.md).

bladecell, 2024-12-16:
I can make the LED light up but I have to connect the b connector on my doorbell to the BUS+ (A) connector on the board and the a connector on the doorbell to the BUS- (B) on the board, otherwise it will not power on.

Then with the "ESPHome Example Configuration" verbatim I am not receiving any messages in the logs or in the HA entity.

Mat931, 2024-12-16:
It's normal for some systems to have A and B swapped, that can't be the reason why you're not receiving anything.
If you soldered the board yourself, you could check the connections and component values, especially on the receiver circuit.

bladecell, 2024-12-18:
Had to resolder a few component but the receiving works now, thanks for the tip.

Closed 2024-12-19.

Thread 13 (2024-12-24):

Board not booting / connecting to wifi

RoMaTiX99, 2024-12-24:
Hello everyone,

I received a PCB that had a broken capacitor (C23) - at least it was lose. During the flashing process I wasn't able to get a connection; however when I (only) connected 18V to the +/- BUS Pins there was no LED flashing (not even the Power LED). So I thought the board would be cracked due to the broken capacitor.

Today I took the time for some further inspections. Here's what I did and what I found out:

- I resoldered the broken capacitor
- I connected 18V DC to the BUS Pins - still no LEDs showing up, not even power LED
- I took external but very stable 5V (and gnd ofc) directly to the ESP Pins and started the flashing process
- Flashing inside HomeAssistant with ESPHome failed; it was not even able to establish a connection
- I downloaded the Make File and flashed it via web.esphome.io; surprisingly this worked!
- After I successfully flashed the board I was looking into the logs since I expected the board to connect with my wifi or give me a fallback hotspot
-  neither was the case - and I can't find anything relevant in the logs (which I can access when I connect the 5V to ESP Pin with the adapter).

The log file is attached [logs (5).txt](https://github.com/user-attachments/files/18240945/logs.5.txt); including 3 (failed) boot iterations. During one boot the log shows the following multiple times, which indicated an hardware error to me:
`[16:44:11]rst:0x7 (TG0WDT_SYS_RESET),boot:0x13 (SPI_FAST_FLASH_BOOT)
[16:44:11]flash read err, 1000
[16:44:11]ets_main.c 371
[16:44:11]ets Jun  8 2016 00:22:57`

For me it looks like the boot process is stuck by loading wifi configuration / modulare:
```
[C][wifi:062]:   Loca
 ets Jun  8 2016 00:22:57
[16:47:18]
[16:47:18]rst:0x1 (POWERON_RESET),boot:0x13 (SPI_FAST_FLASH_BOOT)
[16:47:18]configsip: 0, SPIWP:0xee
[16:47:18]clk_drv:0x00,q_drv:0x00,d_drv:0x00,cs0_drv:0x00,hd_drv:0x00,wp_drv:0x00
[16:47:18]mode:DIO, clock div:2
[16:47:18]load:0x3fff0030,len:6644
[16:47:18]load:0x40078000,len:15056
[16:47:18]ho 0 tail 12 room 4
[16:47:18]load:0x40080400,len:3628
[16:47:18]entry 0x40080668
[16:47:18]I (28) boot: ESP-IDF 4.4.8 2nd stage bootloader
[16:47:18]I (28) boot: compile time 16:38:51
[16:47:18]W (28) boot: Unicore bootloader
[16:47:18]I (31) boot: chip revision: v1.1
[16:47:18]I (35) boot.esp32: SPI Speed      : 40MHz
[16:47:18]I (40) boot.esp32: SPI Mode       : DIO
[16:47:18]I (44) boot.esp32: SPI Flash Size : 4MB
[16:47:18]I (49) boot: Enabling RNG early entropy source...
[16:47:18]I (54) boot: Partition Table:
[16:47:18]I (58) boot: ## Label            Usage          Type ST Offset   Length
[16:47:19]I (65) boot:  0 otadata          OTA data         01 00 00009000 00002000
[16:47:19]I (72) boot:  1 phy_init         RF data          01 01 0000b000 00001000
[16:47:19]I (80) boot:  2 app0             OTA app          00 10 00010000 001c0000
[16:47:19]I (87) boot:  3 app1             OTA app          00 11 001d0000 001c0000
[16:47:19]I (95) boot:  4 nvs              WiFi data        01 02 00390000 0006d000
[16:47:19]I (102) boot: End of partition table
[16:47:19]I (107) esp_image: segment 0: paddr=00010020 vaddr=3f400020 size=21cd4h (138452) map
[16:47:19]I (165) esp_image: segment 1: paddr=00031cfc vaddr=3ffb0000 size=02b00h ( 11008) load
[16:47:19]I (170) esp_image: segment 2: paddr=00034804 vaddr=40080000 size=0b814h ( 47124) load
[16:47:19]I (190) esp_image: segment 3: paddr=00040020 vaddr=400d0020 size=8d930h (579888) map
[16:47:19]I (400) esp_image: segment 4: paddr=000cd958 vaddr=4008b814 size=089f4h ( 35316) load
[16:47:19]I (425) boot: Loaded app from partition at offset 0x10000
[16:47:19]I (425) boot: Disabling RNG early entropy source...
[16:47:19]I (436) cpu_start: Unicore app
[16:47:19]I (437) cpu_start: Pro cpu up.
[16:47:19]I (437) cpu_start: Single core mode
[16:47:19]I (448) cpu_start: Pro cpu start user code
[16:47:19]I (449) cpu_start: cpu freq: 160000000
[16:47:19]I (449) cpu_start: Application information:
[16:47:19]I (453) cpu_start: Project name:     abb-welcome
[16:47:19]I (458) cpu_start: App version:      2024.11.3
[16:47:19]I (464) cpu_start: Compile time:     Dec 24 2024 16:38:19
[16:47:19]I (470) cpu_start: ELF file SHA256:  35fab73e87e09151...
[16:47:19]I (476) cpu_start: ESP-IDF:          4.4.8
[16:47:19]I (480) cpu_start: Min chip rev:     v0.0
[16:47:19]I (485) cpu_start: Max chip rev:     v3.99
[16:47:19]I (490) cpu_start: Chip rev:         v1.1
[16:47:19]I (495) heap_init: Initializing. RAM available for dynamic allocation:
[16:47:19]I (502) heap_init: At 3FFAE6E0 len 00001920 (6 KiB): DRAM
[16:47:19]I (508) heap_init: At 3FFB6BB8 len 00029448 (165 KiB): DRAM
[16:47:19]I (514) heap_init: At 3FFE0440 len 0001FBC0 (126 KiB): D/IRAM
[16:47:19]I (521) heap_init: At 40078000 len 00008000 (32 KiB): IRAM
[16:47:19]I (527) heap_init: At 40094208 len 0000BDF8 (47 KiB): IRAM
[16:47:19]I (533) heap_init: At 3FF80000 len 00002000 (8 KiB): RTCRAM
[16:47:19]I (541) spi_flash: detected chip: generic
[16:47:19]I (544) spi_flash: flash io: dio
[16:47:19]I (549) cpu_start: Starting scheduler on PRO CPU.
[16:47:26][I][logger:171]: Log initialized
[C][status_led:014]: Setting up Status LED...
[D][esp-idf:000]: I (754) gpio: GPIO[2]| InputEn: 0| OutputEn: 1| OpenDrain: 0| Pullup: 0| Pulldown: 0| Intr:0

[C][safe_mode:079]: There have been 3 suspected unsuccessful boot attempts
[D][esp32.preferences:114]: Saving 1 preferences to flash...
[D][esp32.preferences:143]: Saving 1 preferences to flash: 0 cached, 1 written, 0 failed
[I][app:029]: Running through setup()...
[D][lock:054]: 'Front Door': Sending state LOCKED
[C][remote_receiver.esp32:013]: Setting up Remote Receiver...
[D][esp-idf:000]: I (788) gpio: GPIO[25]| InputEn: 1| OutputEn: 0| OpenDrain: 0| Pullup: 0| Pulldown: 0| Intr:0

[C][wifi:048]: Setting up WiFi...
[D][esp-idf:000]: I (802) wifi:
[D][esp-idf:000]: wifi driver task: 3ffc6900, prio:23, stack:6656, core=0
[D][esp-idf:000]:

[D][esp-idf:000][wifi]: I (819) system_api: Base MAC address is not set

[D][esp-idf:000][wifi]: I (828) system_api: read default base MAC address from EFUSE

[D][esp-idf:000][wifi]: I (841) wifi:
[D][esp-idf:000][wifi]: wifi firmware version: ff661c3
[D][esp-idf:000][wifi]:

[D][esp-idf:000][wifi]: I (859) wifi:
[D][esp-idf:000][wifi]: wifi certification version: v7.0
[D][esp-idf:000][wifi]:

[D][esp-idf:000][wifi]: I (869) wifi:
[D][esp-idf:000][wifi]: config NVS flash: enabled
[D][esp-idf:000][wifi]:

[D][esp-idf:000][wifi]: I (890) wifi:
[D][esp-idf:000][wifi]: config nano formating: disabled
[D][esp-idf:000][wifi]:

[D][esp-idf:000][wifi]: I (900) wifi:
[D][esp-idf:000][wifi]: Init data frame dynamic rx buffer num: 32
[D][esp-idf:000][wifi]:

[D][esp-idf:000][wifi]: I (921) wifi:
[D][esp-idf:000][wifi]: Init static rx mgmt buffer num: 5
[D][esp-idf:000][wifi]:

[D][esp-idf:000][wifi]: I (941) wifi:
[D][esp-idf:000][wifi]: Init management short buffer num: 32
[D][esp-idf:000][wifi]:

[D][esp-idf:000][wifi]: I (951) wifi:
[D][esp-idf:000][wifi]: Init dynamic tx buffer num: 32
[D][esp-idf:000][wifi]:

[D][esp-idf:000][wifi]: I (972) wifi:
[D][esp-idf:000][wifi]: Init static rx buffer size: 1600
[D][esp-idf:000][wifi]:

[D][esp-idf:000][wifi]: I (992) wifi:
[D][esp-idf:000][wifi]: Init static rx buffer num: 10
[D][esp-idf:000][wifi]:

[D][esp-idf:000][wifi]: I (1003) wifi:
[D][esp-idf:000][wifi]: Init dynamic rx buffer num: 32
[D][esp-idf:000][wifi]:
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
Mat931, 2024-12-24:
Hi @RoMaTiX99

Did you really connect 5V directly to the ESP32? This could have damaged it since its maximum voltage is 3.6V. Ideally you should use 3.3V to power the ESP32 directly.

The log looks like the ESP32 crashes when it attempts to connect to WiFi. Maybe your power supply can't deliver the current required for WiFi. Does the crash happen when powering the ESP32 directly or are you using the BUS pins and onboard step-down converter?

Maybe there is still a problem with the step-down converter like a broken connection to one of its capacitors. That could explain an unstable voltage that could cause the crash.

RoMaTiX99, 2024-12-25:
Hi @Mat931,

your response times are amazing! Thanks a lot and happy Christmas.

Yes I connected 5V since I’ve never bricked and esp32 by this. Probably this was dumb…

I supply voltage by the esp32 pins when it powers up.
As written, the board won’t power up when I connect 18V DC to the bus pins.

Any idea why this is? So why is there no led when I connect the bus pins.

Best,
Timon

Mat931, 2024-12-25:
For this next step you need a multimeter. Put your multimeter into voltage mode and connect the negative lead to BUS- and the positive to each of the 5 spots in the picture. Power the board over BUS+/BUS- while you measure the voltages. With everything working correctly, 1-4 should be close to your input voltage and 5 should be close to 3.3V. Please tell me the 5 voltages you measured.

Then put your multimeter into resistance mode and measure the resistance between each point and BUS-, this time without powering the board. This can help us find short circuits.

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

RoMaTiX99, 2024-12-26:
Hi @Mat931 ,

here are the results:
Voltage is ok - it fits to the values it should have.

Resistancy:

1: 0,4 kOhm
2: 0,4 kOhm
3: 5,5 MOhm
4: 5,5 MOhm
5: 30 kOhm, but decreasing rapidly, going down to 4 kOhm, probably bc it’s charging a capacitor?

is this anything unusual?

Thanks in advance!

Mat931, 2024-12-26:
In that case I think your ESP32 might be damaged or there's still a broken connection to a capacitor (maybe C23).
If all voltages are ok, the power LED should light up. Is that correct?

RoMaTiX99, 2024-12-26:
Sadly the PowerLED doesn’t light up.

Mat931, 2024-12-26:
Did it ever light up? Maybe it's soldered in reverse or there's a broken trace somewhere.
I'm running out of ideas what could be wrong with your board. Do you have a second board to try?

RoMaTiX99, 2024-12-26:
No, it never lighted up.
I think it’s unlikely that it’s soldered in reverse; it was part of a group buy and it seems like only my board is broken.

Sadly I don’t have another board to try. But if there’s no other way I will order another 5 and give it a try…

Mat931, 2024-12-26:
If your board arrived with a broken capacitor and other problems you can try to get a refund from JLC.
One last thing you can try is to power the board over the BUS pins and measure the voltage on the programming header between 3V3 and GND. If you get 3.3V on position 5 but not on the programming header, you have a broken trace. If there's 3.3V even on the programming header then maybe the LED is broken.

RoMaTiX99, 2025-01-03:
Hi. I have to check, but LED can’t be broken since it lights up when connected via the programming header.

However one last question: what should be the value of the capacitor? I measured 79yF. Is this correct?

Mat931, 2025-01-03:
If you mean C23, that is just outside the range of acceptable values (100µF ±20% -> 80-120µF)
But if that was the only problem, the ESP32 would still work.

RoMaTiX99, 2025-01-06:
Hi again.
I just re-checked everything and I have to correct the measurements of the resistancy:

1: 550 kOhm
2: 540 kOhm
3: Open
4: Open
5: 30kOhm>4kOhm decreasing

and there is more:
I noticed, that on the other capacitor (not the broken one) there was no voltage on the backside pins. So it seemed to have no connection. I wired it to the 3.3V pin of the esp32 and now the WiFi Led did light up for the first time. Any idea?

Next step for me is to check, whether I can get new logs with this setup and what they say (since I can’t see the device in my WiFi nor the fallback hotspot).

RoMaTiX99, 2025-01-11:
Hi @Mat931,

thanks again for all you awesome support. Finally I can give some good news:
I got my board working!

I connected the capacitor to the esp32 3.3V pin so it has stable power connection. Now everything seems to work fine. Will start configuring now. I will close this issue now. Thanks a lot!!!

Closed 2025-01-11.

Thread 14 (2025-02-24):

Failed config with ESPHome 2025.2.0

d-l-h, 2025-02-24:
With `ESPHome 2025.2.0` configuration is failing

    `Failed config

    This feature is only available with frameworks ['arduino'].
    memory_blocks: 5

    This feature is only available with frameworks ['arduino'].
    clock_divider: 160
    on_abbwelcome:
      then:  `

Mat931, 2025-02-24:
I think it should be okay to remove these lines (`memory_blocks` and `clock_divider`). Can you try if it still works with the lines removed? If that doesn't work you can either change the framework to `arduino` or try an ESP-IDF version below 5.0.0.

d-l-h, 2025-02-25:
>remove these lines (`memory_blocks` and `clock_divider`)

This worked fine! Thank you. I created a PR.

Mat931, 2025-02-25:
Thanks for testing!

Closed 2025-02-25.

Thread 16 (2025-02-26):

Remote receiver failed config

bladecell, 2025-02-26:
Hey, I have used the config for several months but now updated and got the error

```
Failed config

remote_receiver: [source /config/esph_abbwelcome.yaml:45]
  - pin:
      number: GPIO25
      mode:
        input: True
    dump:
      - abbwelcome
    filter: 8us
    tolerance:
      type: time
      value: 26us
    idle: 1500us
    buffer_size: 15kB

    This feature is only available with frameworks ['arduino'].
    memory_blocks: 5

    This feature is only available with frameworks ['arduino'].
    clock_divider: 160
    on_abbwelcome:
      then:
```

So I have changed the framework but now the devices does not boot.

bladecell, 2025-02-26:
Did not search the issues :)

Closed 2025-02-26.

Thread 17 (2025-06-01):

Question: any list of verified / supported devices

zeratul021, 2025-06-01:
Project looks great! Went through the docs and was wondering, if there are success stories of installation where it works, including pictures of final wiring and setup. I want to order the board and try it out with my M22002-W-02 model, would love to make it work and contribute to such wiki page.

Mat931, 2025-06-02:
Thanks! I created a [wiki page](https://github.com/Mat931/esp32-doorbell-bus-interface/wiki/Supported-devices). If anyone else has a working device I will add it to the list.

zeratul021, 2025-06-03:
@fischmal thanks! Mine looks like this

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

fischmal, 2025-06-03:
> [@imuncas](https://github.com/imuncas) Personally I have [this red one](https://www.amazon.de/AZDelivery-Adapter-FT232RL-Serial-gratis/dp/B01N9RZK6I), but it doesn't provide enough power for the ESP32 so you need to power the board externally.

I have also used this serial adapter. Worked well with jumper wires ([amazon link](https://www.amazon.de/dp/B01EV70C78)) and the adapter delivered enough power in my case (set the jumper to 3.3).

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

zeratul021, 2025-06-28:
@Mat931 I managed to (with many difficulties due to serial adapter failing to hold 3.3 V, had to use external 12V adapter) flash esp-home and wire the component. So far I haven't been able to catch code for opening doors, but stop ringing button works.
Also, device uses 3 byte addresses, you can update the wiki.

fquinto, 2025-09-30:
@zeratul021 Can you check this?

### RFID Key Messages Found

**Type 0x35 (Short RFID format):**

    Destination: 0x001301 (likely an access controller)

    Data: 02.00 (appears to be a simple code/identifier)

    Example: 55.FF.42.35.00.13.01.00.02.02.7D.02.00.99

**Type 0x60 (Long RFID format with full UID):**

    Destination: 0x000E01 (another access controller)

    Data: 02.01.13.F1.71.B6.00.00.01.01 (10 bytes)

    RFID UID appears to be: 13 F1 71 B6 (the actual chip ID)

    Example: 55.FF.4A.60.00.0E.01.00.02.02.03.02.01.13.F1.71.B6.00.00.01.01.FE

Where the RFID Key Data Is:

In the Type 0x60 message, the RFID key's unique identifier is clearly visible in the data section:

-     Bytes 4-7: 13 F1 71 B6 - This is the actual RFID chip UID
-     The surrounding bytes appear to be facility codes, system identifiers, or other metadata

The Type 0x35 message seems to be a simplified version that might use a shorter, system-specific code rather than the full RFID UID.

So when someone uses an RFID key fob at your front door, the system broadcasts both a short code (0x35) to one controller and the full RFID UID (0x60) to another controller, likely for different purposes like logging vs. immediate access control.

Your RFID key's UID is: **13F171B6**
or maybe **334590390** in RFID print card

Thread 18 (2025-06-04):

Question: Good USB-to-serial adapters

JTorkk, 2025-06-04:
In another [issue](https://github.com/Mat931/esp32-doorbell-bus-interface/issues/17#issuecomment-2936824361) there was discussion about USB-to-serial adapters. I thought it might be helpful to collect confirmed working adapters into this dedicated issue for future reference.

So far, this adapter has been mentioned as working in the above issue: [Amazon link](https://www.amazon.de/AZDelivery-Adapter-FT232RL-Serial-gratis/dp/B01N9RZK6I?th=1)

If you’ve tested other USB-to-serial adapters and can confirm they work (or don’t), please share their details.

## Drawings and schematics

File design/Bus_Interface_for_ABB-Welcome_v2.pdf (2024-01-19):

# GNDEN

IO0 25 IO4 26 IO16 27 IO17 28 IO5 29 IO18 30 IO19 31 NC 32 IO21 33 RXD0 34 TXD0 35 IO22 36 IO23 37 GND 38

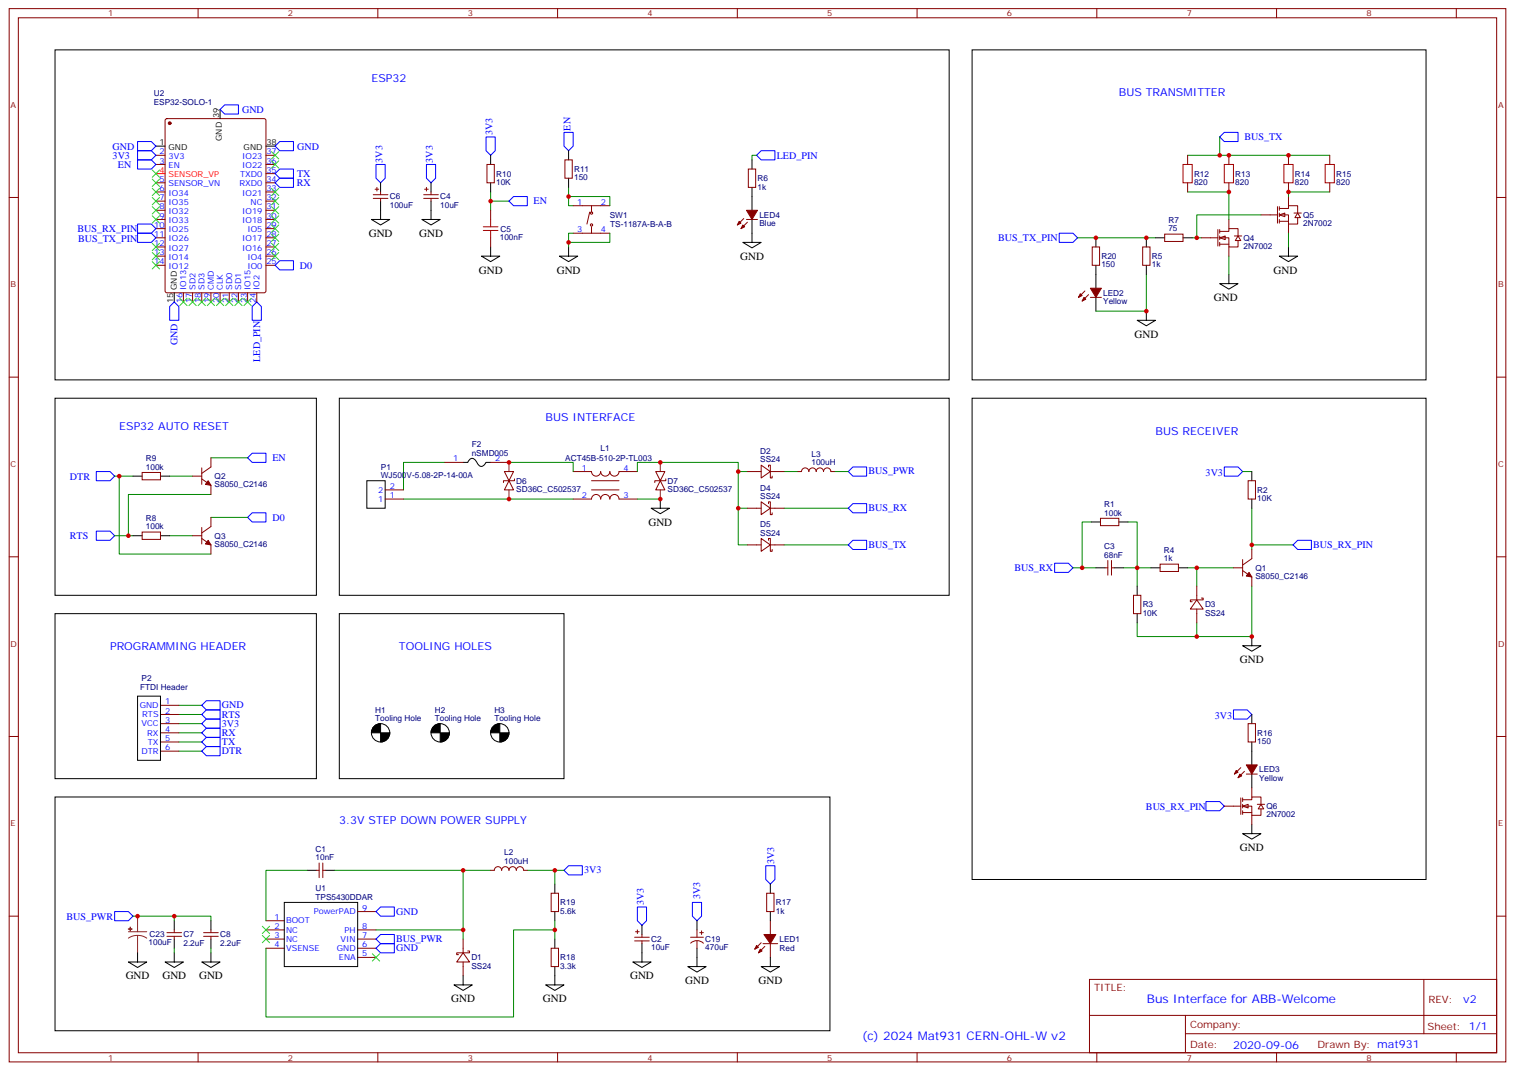
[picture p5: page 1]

3.3V STEP DOWN POWER SUPPLY

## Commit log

2024-02-03 Add missing schematic files
    [Bus_Interface_for_ABB-Welcome_v2.schdoc]
2026-01-21 Update how_to_order.md
    fix: adjusted link for ordering the pcb
2026-01-23 Update config to work with ESPHome 2026.1 and use formattig from esphome-devices
